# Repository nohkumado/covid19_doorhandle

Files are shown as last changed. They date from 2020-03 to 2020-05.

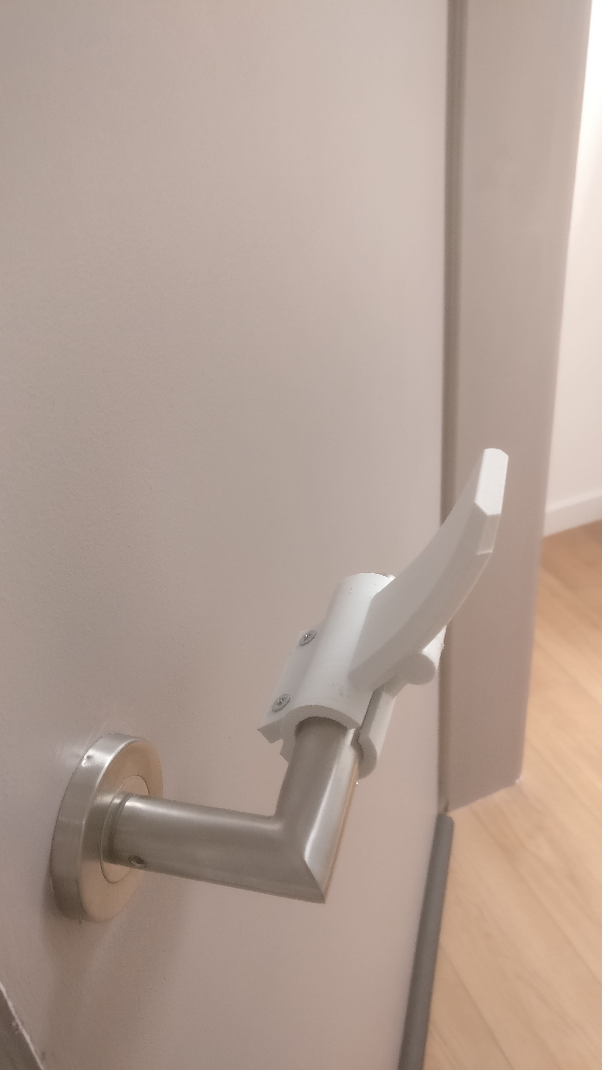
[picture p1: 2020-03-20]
img/IMG_20200320_194411.jpg

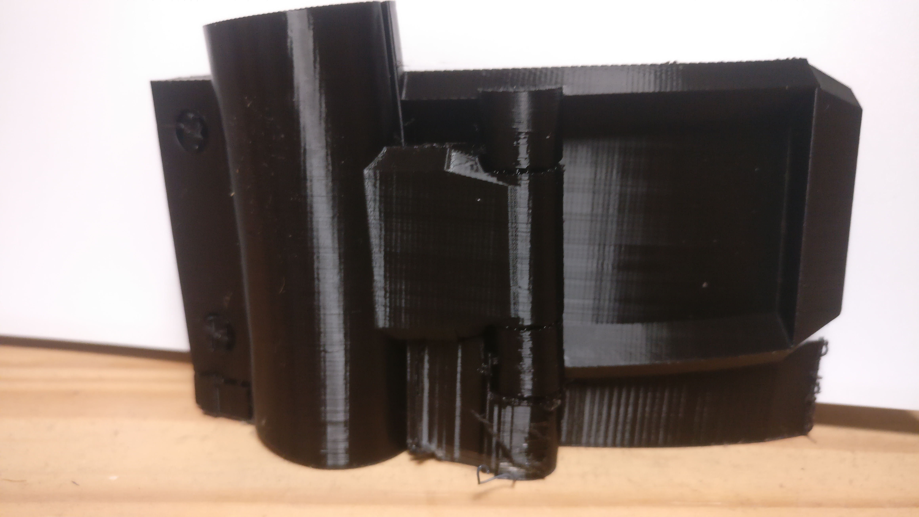
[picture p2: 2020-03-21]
img/IMG_20200321_091850.jpg

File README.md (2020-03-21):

# covid19_doorhandle

inspired by  https://www.materialise.com/en/hands-free-door-opener but i am
using openscad, plus i needed to adapt it to my doorhandles

rationale: places where people get in and out frequently, everyone touches the
doorhandle, even with appropriated metallic coating of certain sorts (copper,
silver etc) the handle is able to desinfect itself in a minimum time of 10 min,
if passage is more often, lets try to not let the handle be touched then.

Here comes this design, instead of using the hand, the forearm is used to make
lever on the handle and to pull the door closed (if you need to push, you can
also use more easily your body).

now on thigieverse : https://www.thingiverse.com/thing:4233677

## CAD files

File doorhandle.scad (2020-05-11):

use <muttern934.scad>
function type2index(norm)=
          (norm == "DIN7991")? 0 :
          (norm == "ISO10642")? 1:
          (norm == "DIN965")? 2:
(norm == "DIN912")? 3:
(norm == "DIN933")? 4: 0;



// DIN7991 = 0;
// ISO10642 = 1;
// DIN965  = 2; //Phillips-Kreuzschlitz PH, DIN 965 (austauschbar mit ISO 7046) Technische Daten für DIN 965 
// DIN912 = 3; // zylinder Kopf Schrauben
// DIN933 = 4; //sechskantkopf


//the width of the rest
width = 50; 
// the height of the thing
size = 120; 
//the thickness, solidity of the knob enclosure
thick = 4;  
//the diameter of the knob
knobdia = 19; 
// the length of the knob (needed especially for courved knobs
knoblen = 135; 
// spacing between the jaws of the thing
luft = 1;     
// the mesure of the deviation from the straight line (together with the length its possible to compute the radius of the knb arc, e.g straigt = 0 , arc = 2.915
hub = 2.9150;
//angle with the knob
fixangle = 30;
//side on which the screws are
screwonleft = true;
//screws metric values!
screwsize = 6;//[1,1.2,1.6,2,2.5,3,4,5,6,8,10]
//screwtype screwnorm : e.g. DIN965/ISO 7046  = 2 (Phillips), DIN912 cylinder head, DIN933  Hexhead 
screwtype = "DIN7991";//["DIN7991","ISO10642","DIN965","DIN912","DIN933"]
//hex gives a hex nut cut, everything else nothing
nuttype = "none"; //["none","hex"]
//add maker logo
addLogo = true;


function radFromHub(sehne,hub) = (hub==0) ? 0 : (sehne /(2*sin(4*(90-atan(sehne/(2*hub))))));

//echo("alpha=",(size*360)/(2*PI*5*width));
//echo("sehne=",(asin(size/(2*5*width))));
//beta = atan(knoblen/(2*hub));
alpha = (hub ==0) ? 0 : 4*(90-atan(knoblen/(2*hub)));
//radius = knoblen /(2*sin(alpha));
knobrad = radFromHub(knoblen,hub);
//echo("rad = ",radius, "knobrad = ",knobrad, " beta = ",beta, " alpha = ",alpha);
module toto() {}//stop function parsing for customizer
$fn = 150;

  rad2quader = sqrt(knobdia*knobdia/2)+luft;

//quadrat shape
//    myshape = [ 
// [-rad2quader/2,-rad2quader/2], 
// [rad2quader/2,-rad2quader/2], 
// [rad2quader/2,+rad2quader/2], 
// [-rad2quader/2,+rad2quader/2], 
//    ];
//F shape
   myshape = [ 
[-rad2quader/2,-rad2quader/2], 
[-rad2quader/2 + 3,-rad2quader/2], 
[-rad2quader/2 + 3,0], 
[-rad2quader/2 + 6,0], 
[-rad2quader/2 + 6,2], 
[-rad2quader/2 + 3,2], 
[-rad2quader/2+3 ,+rad2quader/2 -3], 
[rad2quader/2,+rad2quader/2-3], 
[rad2quader/2,+rad2quader/2], 
[-rad2quader/2,+rad2quader/2], 
   ];

//lever side
 doorknob(lever = true, clear = 1,hexonleft = screwonleft, metrisch=screwsize,styp = type2index(screwtype), ntyp = nuttype, logo = addLogo)
 {
    //put here the shape of your handlet will be diffed with  knob(knobdia, width,knobrad, thick = thick, outside = true);
    knob(knobdia, knoblen,knobrad, thick = thick, outside = false, poly = myshape, angle = fixangle);
    //cube([.8*knobdia, knoblen+2, .8*knobdia], center = true);
 }

 //handle side
 doorknob(lever = false, clear = 1,hexonleft = screwonleft, metrisch=screwsize,styp = type2index(screwtype), ntyp = nuttype, logo = false)
           knob(knobdia, knoblen,knobrad, thick = thick, outside = false, poly = myshape, angle = fixangle);
    //cube([.8*knobdia, knoblen+2, .8*knobdia], center = true);



    //knob(knobdia, knoblen,knobrad, thick = thick, outside = false, poly = myshape);

/*
   knob,
   if you have a special shape, add it here!
 */
function adjDiam(diam, thick, luft, side) = (side)? diam+2*thick+2*luft : diam+luft;
function adjLen(len, side) = (side)? len : len+2;
function adjRad(rad, side) = (side)? rad : 2*rad;

module knob(knobdia, len, knobrad, thick, outside = true, poly = [], angle = -70)
{
  //knob(knobdia+2*thick+2*luft, width,knobrad, thick = thick, outside = true);
  if(knobrad == 0)
  {
    rotate([0,angle,0])//change here 90 for perfecly vertical, 90-20, to have enough space to go trough with the arm
    translate([0,adjLen(len)/2,0])
      rotate([90,0,0])
      if(len(poly) >  0 &&!outside)
{
echo("found poly");
      linear_extrude(height=len) polygon(poly);
      //cylinder(d=adjDiam(knobdia,thick,luft,outside), h=len);
}
      else
      cylinder(d=adjDiam(knobdia,thick,luft,outside), h=len);
  }
  else
  {
    rotate([0,angle,0])//change here 90 for perfecly vertical, 90-20, to have enough space to go trough with the arm
      translate([-adjRad(knobrad,outside),0,0])
      rotate([0,0,-alpha/2])
      rotate_extrude(angle=alpha)
      translate([adjRad(knobrad,outside),0,0])
      if(len(poly) >  0 &&!outside)
{
      polygon(poly);
}
      else
      circle(d=adjDiam(knobdia,thick,luft,outside));
  }
}

module doorknob(lever = true, clear = 0.5,hexonleft = false,metrisch = 4, styp = type2index("DIN7991"), ntyp = "hex", logo = true)
{
  lhx = 4;
  lhz = 1.665;
  rhx = 4;
  rhz = 1.665;
  difference()
  {
    union()
    {
      beta =(size*360)/(2*PI*5*width);
      if(lever)
      {
        //beta =asin(size/(2*5*width));
        //translate([2*thick+2,0,(knobdia+thick)/2])
        translate([thick+2,0,(knobdia+thick)/2])
          rotate([0,-10,180])
          armlever(w= width, thick=thick, angle=beta, logo = logo);
        translate([rhx,0,rhz*knobdia]) outerHinge(dia=12, w=0.9*width);
      }
      else
      {
        translate([-thick,0,(knobdia+thick)/2-1])
          rotate([0,22,0])
          armlever(w= width*.6, thick=thick, angle=beta/3, logo= false);
        translate([lhx,0,lhz*knobdia]) innerHinge(dia=12, w=0.9*width);
      }
          flanschhoehe = max(0.8*knobdia,2*metrisch+4);
          flanschbreite = max(width,4*metrisch+20);
          flanschtiefe = max(4*thick,mschraubmass(styp,metrisch)[3]+mmuttermass(metrisch)[1]+2*clear+2*thick); 
          stiefe = max(30,flanschtiefe+10);
echo(str("act:",4*thick," vs ",flanschtiefe));
      difference()
      {
        union()
        {
          knob(knobdia, width,knobrad, thick = thick, outside = true);
          echo(str("flansch daten (",metrisch,") ",4*thick),width,flanschhoehe,flanschbreite);
          translate([0,0,-knobdia-(flanschhoehe-0.8*knobdia)/2-metrisch*cos(30)/2])//flansch
            cube([flanschtiefe,flanschbreite,flanschhoehe+metrisch*cos(30)],center = true);
          //cube([4*thick,knoblen/2,0.8*knobdia],center = true);
        }
        union()
        {
          //color("magenta")
          children(); //the doorhandle shape to remove
          if(lever)
          {
            translate([-0.75*knobdia+clear,0,0])
              cube([1.5*knobdia,knoblen+2,2*size],center = true);
          }
          else
          {
            translate([0.75*knobdia-clear,0,0])
              cube([1.5*knobdia,knoblen+2,2*size],center = true);
          }
          mittez =  -knobdia/2-flanschhoehe/2-metrisch*cos(30)/2;
          //mittez =  -knobdia/2-flanschhoehe/2-metrisch*cos(30);
          if(hexonleft)
          {
            if(ntyp == "hex")
            {
              translate([-flanschtiefe/2-.1,flanschbreite/4,mittez]) rotate([0,90,0]) metrische_mutter_schablone(metrisch,30, 0.1);
              translate([-flanschtiefe/2-.1,-flanschbreite/4,mittez]) rotate([0,90,0]) metrische_mutter_schablone(metrisch,30, 0.1);
            }

            translate([flanschtiefe/2+2,flanschbreite/4,mittez]) rotate([0,-90,0]) metrische_schraube_schablone(typ = styp , mass= metrisch,laenge = stiefe, toleranz = 0.1);
            translate([flanschtiefe/2+2,-flanschbreite/4,mittez]) rotate([0,-90,0]) metrische_schraube_schablone(typ = styp , mass= metrisch,laenge = stiefe, toleranz = 0.1);
          }
          else
          {
            if(ntyp == "hex")
            {
              //flanschtiefe = max(4*thick,mschraubmass(styp,metrisch)[3]+mmuttermass(metrisch)[1]+2*clear+2*thick); 
              translate([flanschtiefe/2-0.9*mmuttermass(metrisch)[1],flanschbreite/4,mittez]) rotate([0,90,0]) metrische_mutter_schablone(metrisch,30,  0.1);
              translate([flanschtiefe/2-0.9*mmuttermass(metrisch)[1],-flanschbreite/4,mittez]) rotate([0,90,0]) metrische_mutter_schablone(metrisch,30,  0.1);
            }
            translate([-flanschtiefe/2-0.1,flanschbreite/4,mittez])  rotate([0,90,0]) metrische_schraube_schablone(typ = styp , mass= metrisch,laenge = stiefe, toleranz = 0.1);
            translate([-flanschtiefe/2-0.1,-flanschbreite/4,mittez]) rotate([0,90,0]) metrische_schraube_schablone(typ = styp , mass= metrisch,laenge = stiefe, toleranz = 0.1);
          }
        }
      }
    }
    if(lever)
    {
      color("magenta")
        translate([rhx,0,rhz*665*knobdia]) innerHinge(dia=12+clear, w=0.9*width);
    }
    else
    {
      color("magenta")
        translate([lhx,0,lhz*knobdia]) outerHinge(dia=12+clear, w=0.86*width);
    }
  }
}
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

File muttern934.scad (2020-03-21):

/*

   Sechskantmuttern nach DIN 934
   change the m variable below to adjust to the M value you want
   startw is the angle to add, if you want a certain orientation of the nut shape

   add use <muttern934.scad> in your source to add this library
   metrische_mutter_schablone(5,startw = 30, toleranz = 0.1); //creates a M5 nut, rotated by 30deg and with an added .1 width

 */
//  metrische_mutter_schablone(5,startw = 30, toleranz = 0.1); //creates a M5 nut, rotated by 30deg and with an added .1 width
//translate ([12,00,0])metrische_schraube_schablone(typ = DIN7991, mass= 5,laenge = 30, toleranz = 0.1);

DIN7991 = 0;
ISO10642 = 1;
DIN965  = 2; //Phillips-Kreuzschlitz PH, DIN 965 (austauschbar mit ISO 7046) Technische Daten für DIN 965 
DIN912 = 3; // zylinder Kopf Schrauben
DIN933 = 4; //sechskantkopf


//name dicke zangenbreite
masse = [
  [1,  0,8,2,5], //M1
  [1.2,    1, 3], //M1.2
  [1.4,    1,2, 3	 ], //M1.4
  [1.6,    1,3, 3,2], //M1.6
  [1.7,    1,4, 3,5], //M1.7
  [2,    1,6, 4	 ], //M2
  [2.3,    1,8, 4,5], //M2.3
  [2.5,  2, 5], //M2.5
  [2.6,  2, 5], //M2.6
  [3,  2.4, 5.5], //M3
  [3.5,  2.8, 6  ], //M3.5
  [4  ,  3.2, 7  ], //M4  
  [5  ,  4  , 8  ], //M5  
  [6  ,  5  , 10 ], //M6  
  [7  ,  5.5, 11 ], //M7  
  [8  ,  6.5, 13 ], //M8  
  [10 ,  8  , 17 ], //M10 
  [12 ,  10 , 19 ], //M12 
  [14 ,  11 , 22 ], //M14 
  [16 ,  13 , 24 ], //M16 
  [18 ,  15 , 27 ], //M18 
  [20 ,  16 , 30 ], //M20 
  [22 ,  18 , 32 ], //M22 
  [24 ,  19 , 36 ], //M24 
  [26 ,  22 , 41 ], //M26 
  [27 ,  22 , 41 ], //M27 
  [30 ,  24 , 46 ], //M30 
  [33 ,  26 , 50 ], //M33 
  [36 ,  29 , 55 ], //M36 
  [39 ,  31 , 60 ], //M39 
  [42 ,  34 , 65 ], //M42 
  [45 ,  36 , 70 ], //M45 
  [48 ,  38 , 75 ], //M48 
  [50 ,  38 , 75 ], //M50 
  [52 ,  42 , 80 ], //M52 
  [56 ,  45 , 85 ], //M56 
  [60 ,  48 , 90 ], //M60 
  [64 ,  51 , 95 ], //M64 
  [68 ,  54 , 100], //M68 
  [72 ,  58 , 105], //M72 
  [76 ,  61 , 110], //M76 
  [80 ,  64 , 115], //M80 
  [85 ,  68 , 120], //M85 
  [90 ,  72 , 130], //M90 
  [95 ,  75 , 135], //M95 
  [100,  80 , 145], //M100
  [105,  82 , 150], //M105
  [110 ,  88 , 155], //M110 
  [120 ,  95 , 175], //M120 
  ];



schrauben = 
[
  //Senkschraubendaten nach DIN 7991
  // M  ∅ Senkloch,∅ Durchgang, min. Senk-Tiefe
  [
    [  3,	 6.00,	 3.40,	1.70,],
    [  4,  8.00,	 4.50,	2.30,],
    [  5, 10.00,   5.50 , 2.80 ],
    [  6, 12.00,	 6.60 , 3.30 ],
    [  8, 16.00,   9.00,  4.40 ],
    [ 10, 20.00,	11.00,	5.50 ],
    [ 12, 24.00,	13.50,	6.50 ],
    [ 14, 30.00,  15.50,  7.50 ],
    [ 16, 30.00,	17.50,	7.50 ],
    [ 20, 36.00 , 22.00 , 8.50 ],
    [ 22, 36.00,  24.00, 13.10 ],
    [ 24,39,00 ,  26.00 ,14.00 ]
  ],
  //Bohrtabelle für Senkschrauben nach DIN-EN-ISO 10642 – Form B∅ 
  [
    //Gewinde	        ∅ Senkloch	    ∅ Durchgang	    min. Senk-Tiefe	
    [ 3	,  6.72,	 3.40, 	1.90],
    [ 4	,  9.00,	 4.50, 	2.50],
    [ 5	, 11.20,	 5.50, 	3.10],
    [ 6	, 13.50,	 6.60, 	3.80],
    [ 8	, 18.00,	 9.00, 	5.00],
    [ 10, 22.40,	11.00, 	6.20],
    [ 12, 26.80,	13.50, 	7.45],
    [ 14, 30.88,	15.50, 	8.80],
    [ 20, 40.32,	22.00, 10.20],
    [ 22, 36.00,	24.00, 13.10],
    [ 24, 39.00,  26.00, 14.00] 
  ],
  [
    //Senkschrauben mit Phillips-Kreuzschlitz PH DIN 965 (austauschbar mit ISO 7046) Technische Daten für DIN 965 
    //Maße	,   dk	      durch	 ,  kopfhoehe	        
    [ 1,  2.3, 1.6, 0.96],
    [ 2,  3.8, 2,   1.2	],
    [ 3,  5.6, 3,   1.65 ],
    [ 4,  7.5, 4,   2.2  ],
    [ 5,  9.2, 5,   2.5	],
    [ 6, 11,   6,   3	],
    [ 8, 14.5, 8,   4	],
    [10, 18  ,10,   5	 ],
    [12, 22	 ,12,   6	],
    [16, 29  ,16,   8]
  ],
  [
    //DIN 912 Technisches Datenblatt Innensechskantschrauben nach Norm mit ISO Regelgewinde oder ISO Feingewinde
    //Gewinde Kopfdurchmesser Kopfdurchmesser Kopfhöhe
    [1.4 	,2.60,2.60,1.40],
    [1.6 	,3.00,3.00,1.60],
    [2	 	,3.80,3.80,2.00],
    [2.5 	,4.50,4.50,2.50],
    [3	 	,5.50,5.50,3.00],
    [4	 	,7.00,7.00,4.00],
    [5	 	,8.50,8.50,5.00],
    [6	 	,10.0,10.0,6.00],
    [8	 	,13.0,13.0,8.00],
    [10	 	,16.0,16.0,10.0],
    [12	 	,18.0,18.0,12.0],
    [14	 	,21.0,21.0,14.0],
    [16	 	,24.0,24.0,16.0],
    [18	 	,27.0,27.0,18.0],
    [20	 	,30.0,30.0,20.0],
    [22	 	,33.0,33.0,22.0],
    [24	 	,36.0,36.0,24.0],
    [27	 	,41.0,41.0,27.0],
    [30	 	,45.0,45.0,30.0],
    [33	 	,51.0,51.0,33.0],
    [36	 	,54.0,54.0,36.0],
    [42	 	,63.0,63.0,42.0],
    [48	 	,72.0,72.0,48.0],
    [56	 	,84.0,84.0,56.0]
    ],
    //Sechskantschrauben DIN 933
    [
      [2, 4, 4, 1.4],
      [3, 5.5, 5.5, 2],
      [4, 7, 7, 2.8],
      [5, 8, 8, 3.5],
      [6, 10, 10, 4],
      [7, 11, 11, 4.8],
      [8, 13, 13, 5.3],
      [10, 17, 17, 6.4],
      [12, 19, 19, 7.5],
      [14, 22, 22, 8.8],
      [16, 24, 24, 10],
      [18, 27, 27, 11.5],
      [20, 30, 30, 12.5],
      [22, 32, 32, 14]
    ]
    ];


//name dicke zangenbreite
function  mmuttermass(mass)= masse[search(mass, masse, num_returns_per_match=0, index_col_num=0)[0]];
module metrische_mutter_schablone(mass,startw = 30, toleranz = 0, ueberlaenge = false)
{
  winkel = 360/6;		// 6 Ecken

  data = masse[search(mass, masse, num_returns_per_match=0, index_col_num=0)[0]];
  //echo("benutze Daten ",data);

  sechseck= [for(i = [1 : 6]) [
    (data[0]+toleranz)*cos(i*winkel+startw), (data[0]+toleranz)*sin(i*winkel+startw)] ];
  //(data[2]+toleranz)*cos(i*winkel+startw), (data[2]+toleranz)*sin(i*winkel+startw)] ];
  if(ueberlaenge)
  {
    linear_extrude(height = 2*data[1]+2*toleranz) polygon(sechseck);
  }
  else
  {
    linear_extrude(height = data[1]+2*toleranz) polygon(sechseck);
  }
}
  // M  ∅ Senkloch,∅ Durchgang, min. Senk-Tiefe
function  mschraubmass(typ,mass)= schrauben[typ][search(mass, schrauben[typ], num_returns_per_match=0, index_col_num=0)[0]];
module metrische_schraube_schablone(typ, mass,laenge = 30, toleranz = 0)
{
  $fn = 100;
  data = schrauben[typ][search(mass, schrauben[typ], num_returns_per_match=0, index_col_num=0)[0]];
  if(typ == DIN933)
  {
    metrische_mutter_schablone(mass=data[0], startw = 30, toleranz = toleranz, ueberlaenge = false);
  }
  else
  {
    cylinder(d1=data[1]+toleranz, d2=data[2]+toleranz, h= 2*data[3]);
  }

  translate([0,0,data[3]]) cylinder(d=data[0]+toleranz, h= laenge);
}

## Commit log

2020-03-18 added hex bolt mask to make approiated reservations
    [muttern934.scad]
2020-03-18 rough form of the armlever
    [doorhandle.scad, muttern934.scad]
2020-03-18 added bottom fixation
    [doorhandle.scad]
2020-03-19 prior to printing, should be ok...
    [doorhandle.scad, muttern934.scad]
2020-03-19 with a hinge on one side instead of 2 screws
    [doorhandle.scad]
2020-03-19 added rounded handles possibility
    [doorhandle.scad, muttern934.scad]
2020-03-19 removed comments, made a func to compute the radius
    [doorhandle.scad]
2020-03-19 cleaned up the hinge part, added more air between the elements, they sticked when printing,,,,
    [doorhandle.scad, muttern934.scad]
2020-03-20 well..... the handle was the wrong side up....
    [doorhandle.scad]
2020-03-20 reinverted the holes for the screws, either i find some screws with handles that can be tightened by hand, or print some kno for screws, i don't like the screws protruding on the side of the hand, bu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
    [doorhandle.scad]
2020-03-21 removed the sputter at the end of the claw, added a photo with supports
    [doorhandle.scad]
2020-03-21 well just inverting the positions for the screws didn't make it, left the lines in it for left side screw, to change just move the comments to the lines below
    [doorhandle.scad]
2020-03-21 made the screw handling parametrized, also the side of the screw can now be choosen at the beginning of the file
    [doorhandle.scad, muttern934.scad]
2020-05-11 added logo
    [doorhandle.scad]
2020-05-11 added polygon shapes to possible knob configurations
    [doorhandle.scad]
